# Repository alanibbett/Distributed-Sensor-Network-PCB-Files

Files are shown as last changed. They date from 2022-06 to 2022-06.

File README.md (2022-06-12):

# Distributed-Sensor-Network-PCB-Files
PCB files in eagle PCB format and Gerber for the sensor board of the DSN 
This repository contains the PCB design files for a simple raspberry PI expansion board. 
This design does not comply with the specifications of a RaspberryPi Hat but does support contain the following items:

*	OLED Display to indicate system status: the OLED provides a way to display a simple menu based user interface
*	RFM9x LoRa radio: Provides a network connection to LoRaWAN or other LoRa nodes
*	Global Position System GPS receiver: Allows the node to accurately collect UTC time and date as well as location information of other data captured (GPS)
*	DC power supply input connector: To supply regulated 5VDC to the system
*	LED: Status LED – shows system status at a glance
*	GPIO: 5 of the RaspberryPI GPIO pins have been broken out in a Signal-Voltage-Ground (SVG) layout for connecting to external devices. These can include relays, sensors, switches and so forth.
*	Keypad: A three button keypad for interacting with the OLED menu user interface.

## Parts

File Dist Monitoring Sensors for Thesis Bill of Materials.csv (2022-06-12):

Part | Value | Device | Package | Description | MPN | PROD_ID | SF_SKU | VALUE
D1 | 1N4004 | 1N4004 | DO41-10 | DIODE
DC1 | 2.1 mm | DCBARRELPTH | DCJACK_2MM_PTH | 2.0mm DC Barrel Jack
DISP1 | OLED | DISPLAY-OLED-128X64-I2C | DISPLAY-OLED-128X64-I2C | 128x64 Dot Matrix OLED Module based on SSD1306 chip
GPS1 | GPS | GPS-RECEIVER-NEO6MGENERIC | GPS-RECEIVER-NEO6M-GENERIC | Generic GPS Receiver Module based on NEO-6 device
H1 | G | CONN_05 | 1X05 | Multi connection point. Often used as Generic Header-pin footprint for 0.1 inch spaced/style header connections
H2 | V | CONN_05 | 1X05 | Multi connection point. Often used as Generic Header-pin footprint for 0.1 inch spaced/style header connections
H3 | S | CONN_05 | 1X05 | Multi connection point. Often used as Generic Header-pin footprint for 0.1 inch spaced/style header connections
H4 | I2C | DIP-BLACK-MALE-HEADER-VERT(4P-2.54) | H4-2.54 | 320020017 | P125-1104A0BS116A1 |  |  | 4p-2.54
LED1 | White | LED3MM | LED3MM | LED
R1 | 220R | R-US_0207/10 | 0207/10 | RESISTOR, American symbol
S1 |  | MOMENTARY-SWITCH-SPST-PTH-6.0MM | TACTILE_SWITCH_PTH_6.0MM | Momentary Switch (Pushbutton) - SPST |  | SWCH-08441 | COM-00097
S2 |  | MOMENTARY-SWITCH-SPST-PTH-6.0MM | TACTILE_SWITCH_PTH_6.0MM | Momentary Switch (Pushbutton) - SPST |  | SWCH-08441 | COM-00097
S3 |  | MOMENTARY-SWITCH-SPST-PTH-6.0MM | TACTILE_SWITCH_PTH_6.0MM | Momentary Switch (Pushbutton) - SPST |  | SWCH-08441 | COM-00097
U1 | RFM95W | RFM95W | RFM95W | Adafruit LORA Packet Radio
X1 | Raspi 40 Pin Connector | RASPI_BOARD_B+#_E3P | RASPI_BOARD_B+_EDGES_3DRILL_PAD | Raspberry Pi GPIO connector with markings for the outer dimensions of the Raspberry Pi board model B+

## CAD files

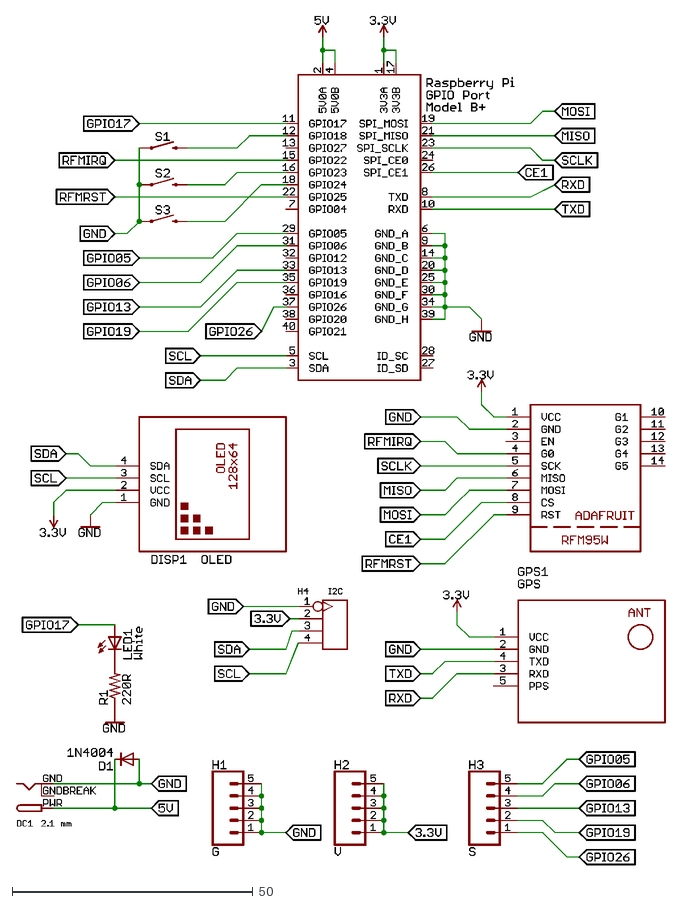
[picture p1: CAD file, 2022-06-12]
Dist Monitoring Sensors for Thesis.dxf
134.9 x 176.4

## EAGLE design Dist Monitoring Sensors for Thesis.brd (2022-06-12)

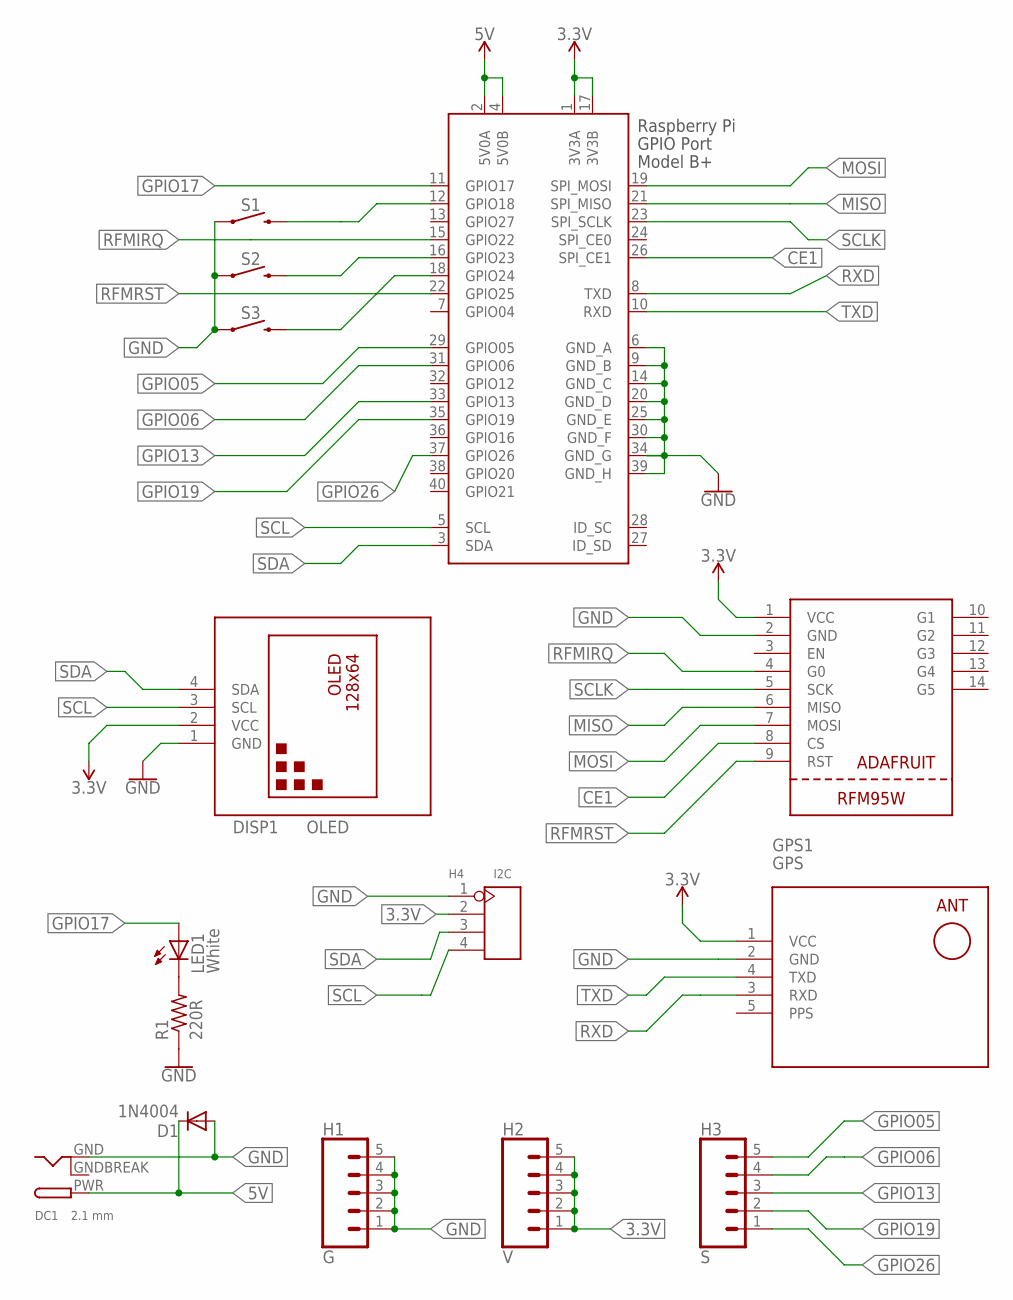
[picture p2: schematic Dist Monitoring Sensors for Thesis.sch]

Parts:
D1: 1N4004; DO41-10
DC1: 2.1 mm; DCJACK_2MM_PTH
DISP1: OLED; DISPLAY-OLED-128X64-I2C
GPS1: GPS; GPS-RECEIVER-NEO6M-GENERIC
H1: G; 1X05
H2: V; 1X05
H3: S; 1X05
H4: I2C; H4-2.54
LED1: White; LED3MM
R1: 220R; 0207/10
S1, S2, S3: MOMENTARY-SWITCH-SPST-PTH-6.0MM; TACTILE_SWITCH_PTH_6.0MM
U1: RFM95W
X1: Raspi 40 Pin Connector; RASPI_BOARD_B+_EDGES_3DRILL_PAD

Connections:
3.3V: DISP1.2 (VCC), GPS1.1 (VCC), H2.1, H2.2, H2.3, H2.4, H2.5, H4.2, U1.1 (VCC), X1.1 (3V3A), X1.17 (3V3B)
5V: D1.C, DC1.PWR, X1.2 (5V0A), X1.4 (5V0B)
CE1: U1.8 (CS), X1.26 (SPI_CE1)
GND: D1.A, DC1.GND, DISP1.1 (GND), GPS1.2 (GND), H1.1, H1.2, H1.3, H1.4, H1.5, H4.1, R1.1, S1.1, S2.1, S3.1, U1.2 (GND), X1.6 (GND_A), X1.9 (GND_B), X1.14 (GND_C), X1.20 (GND_D), X1.25 (GND_E), X1.30 (GND_F), X1.34 (GND_G), X1.39 (GND_H)
GNDBREAK: DC1.GNDBREAK
GPIO05: H3.5, X1.29 (GPIO05)
GPIO06: H3.4, X1.31 (GPIO06)
GPIO13: H3.3, X1.33 (GPIO13)
GPIO17: LED1.A, X1.11 (GPIO17)
GPIO18: S1.3 (2), X1.12 (GPIO18)
GPIO19: H3.2, X1.35 (GPIO19)
GPIO23: S2.3 (2), X1.16 (GPIO23)
GPIO24: S3.3 (2), X1.18 (GPIO24)
GPIO26: H3.1, X1.37 (GPIO26)
MISO: U1.6 (MISO), X1.21 (SPI_MISO)
MOSI: U1.7 (MOSI), X1.19 (SPI_MOSI)
unnamed: LED1.K (C), R1.2
RFMIRQ: U1.4 (G0), X1.15 (GPIO22)
RFMRST: U1.9 (RST), X1.22 (GPIO25)
RXD: GPS1.3 (RXD), X1.8 (TXD)
SCL: DISP1.3 (SCL), H4.4, X1.5 (SCL)
SCLK: U1.5 (SCK), X1.23 (SPI_SCLK)
SDA: DISP1.4 (SDA), H4.3, X1.3 (SDA)
TXD: GPS1.4 (TXD), X1.10 (RXD)

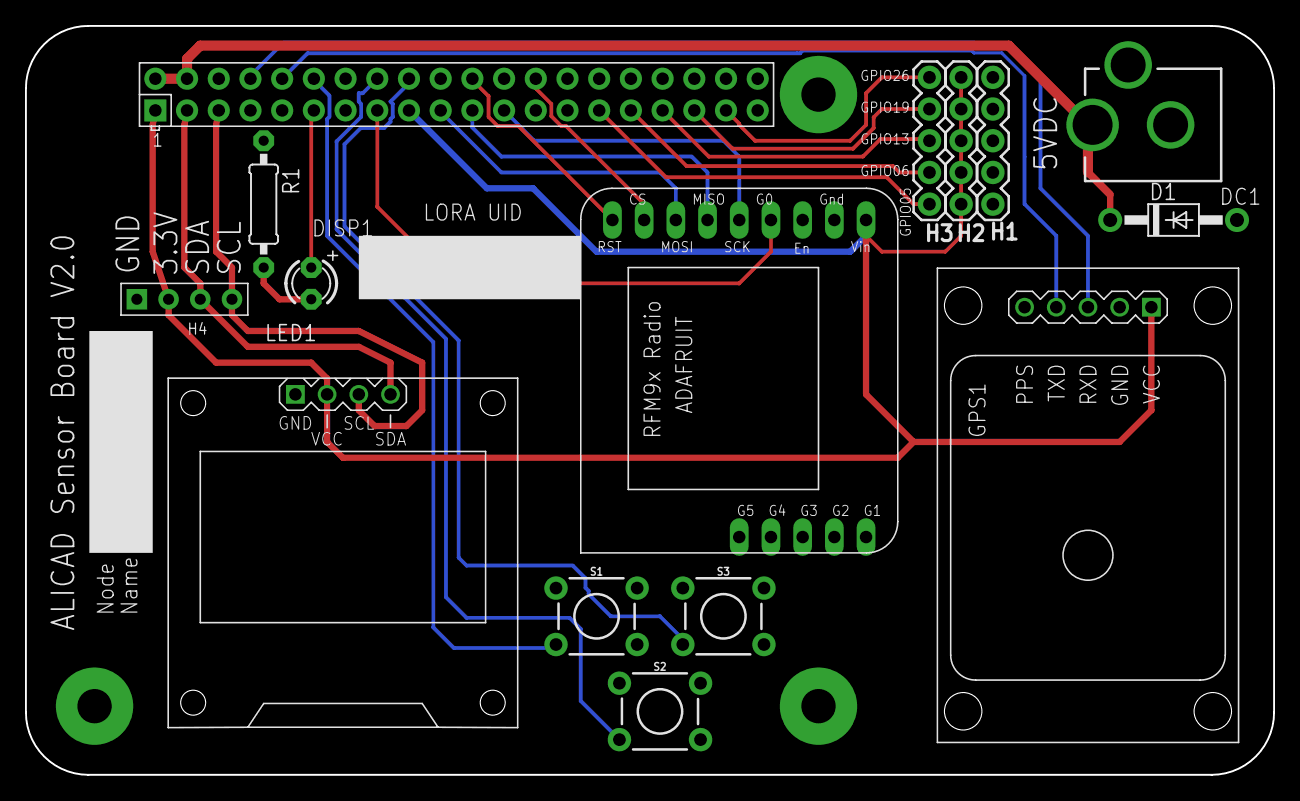
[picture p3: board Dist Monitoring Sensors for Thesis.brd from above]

Board: 2 copper layers, 100.0 x 60.0 mm, 15 parts (0 on the bottom side), 23 nets.

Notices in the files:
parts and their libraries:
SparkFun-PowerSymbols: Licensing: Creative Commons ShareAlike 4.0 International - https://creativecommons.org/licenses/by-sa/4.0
